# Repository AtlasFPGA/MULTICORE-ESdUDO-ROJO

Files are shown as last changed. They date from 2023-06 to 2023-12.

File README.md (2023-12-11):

# MULTICORE-ESdUDO-ROJO
Diseñar la placa - ¡Créalo tu mismo! de coste más reducido para la Fpga CYC1000 con una bluepill STM32F103C8T6

# https://t.me/INICIATIVAATLAS -> El grupo ATLAS esta en Telegram pueden encontrarnos allí, Group ATLAS in Telegram

Escudo ROJO (https://youtu.be/kMc1XR39d8Y)

   Se muestra el multicore en desarrollo para cyc1000 de arrow/trenz el cual aloja una fpga Cyclone 10 LP de intel con 25kles y 66 bloques de Bram de 9Kbytes, tiene integrada una memoria de celular de bajo consumo y reducida latencia, siendo una sdram a 166Mhz con 8MBytes en un bus de 16bits, La familia Cyclone 10 LP permite implementar modelos que superan los 400Mhz en sus diseños, manteniendo un bajo consumo. 
También hay que disponer de una bluepill con un STM32F103C8Tx, posee 64Kbytes de Flash y 20Kbytes de sram, con una unidad de proceso ARM cortex M3 de 32bit funcionando a 72Mhz. 

---
# Esquema analógico totalmente configurable por el usuario en el vídeo compuesto de 512 colores.

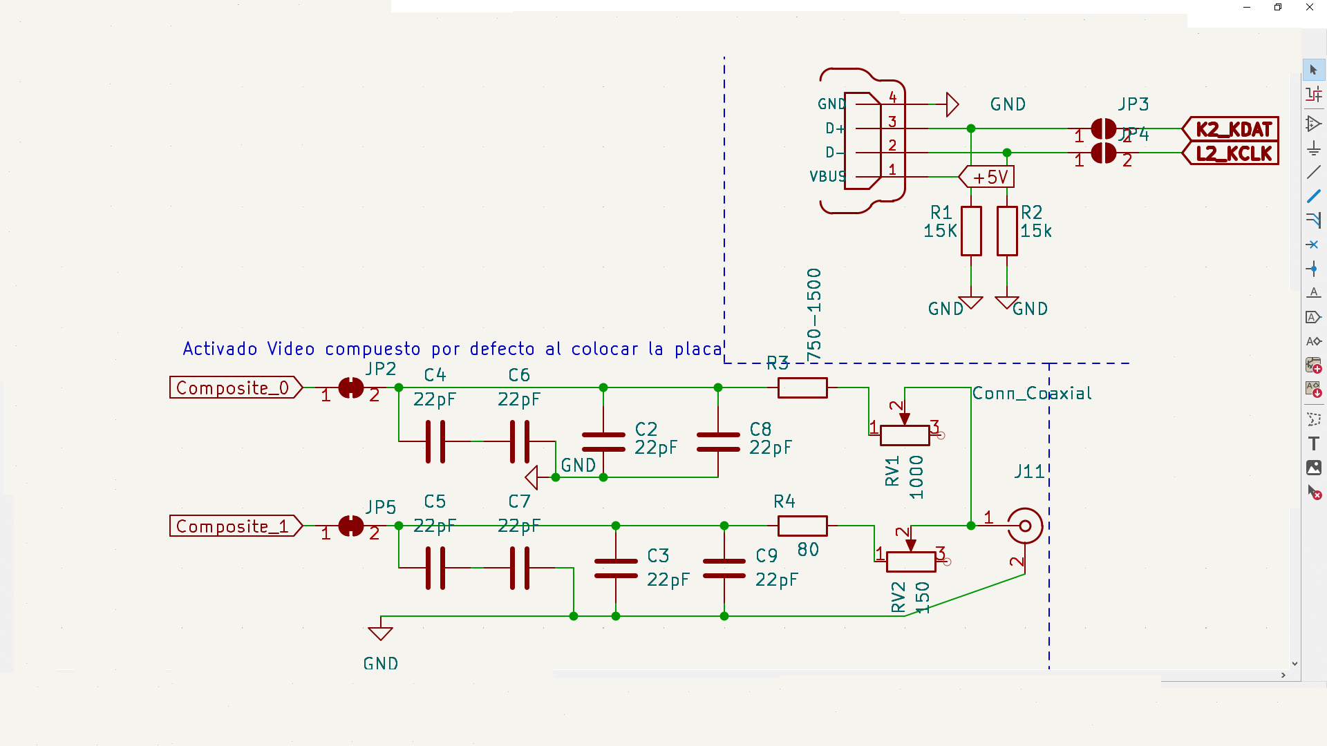
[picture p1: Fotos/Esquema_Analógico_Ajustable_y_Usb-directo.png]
Ajuste ANALÓGICO VIDEO COMPUESTO


Nota:

Creamos una tabla para proceder con el ajuste analógico de la salida de vídeo compuesto.

| R3  | RV1 | VALOR RESISTIVO RAMA COMPOSITE 0  | R4  | RV2  |  VALOR RESISTIVO RAMA COMPOSITE 1|
|:---:|---:|---:|---:|---:|---:|
|750 Ohm|0 Ohm|750 Ohm| 80 Ohm| 0 Ohm|80 Ohm|
|1500 Ohm|1000 Ohm|2500 Ohm|80 Ohm|150 Ohm|230 Ohm|

Para Composite 0 la corriente máxima se obtiene con 750 Ohm -> +3,3V/(750_Ohm)= 0,0044 Amperios

Para Composite 0 la corriente mínima se obtiene con 2500 Ohm -> +3,3V/(2500_Ohm)= 0,00132 Amperios

Para Composite 1 la corriente máxima se obtiene con 80 Ohm -> +3,3V/(80_Ohm)= 0,04125 Amperios -> La CYCLONE 10 LP esta limitada a 12Miliamperios ¿Lo fundimos?

Para Composite 1 la corriente mínima en el diseño propuesto se obtiene con 230 Ohm -> +3,3V/(230_Ohm)= 0,014347926 Amperios -> Por encima de la limitación de corriente 12Miliamperios

Luego hay que calcular que valores de resistencia usar, en Composite 1 en las dos posiciones extremas se drena más corriente por pin.
También vemos que aporta más corriente Composite1 un valor más fuerte que Composite0, por lo que tenemos bien ordenadas las lineas por donde van las señales, pero al ser hardware programable, imaginamos que nos equivocamos, esta es una de las grandes cualidades de una FPGA, con una simple reordenadión de pineado y reetiquetado todo funciona perfectamente,es por esto que muchos diseños actualmente son programables ya sean microcontroladores, cplds o fpgas.

Luego la pregunta es, que resistencia en serie a +3,3V coloco para no fundir un pin de... ¿la preciada FPGA?
doce miliamperios = 0,012_Amperios = +3,3_Voltios/Resistencia_protección_pin

Resistencia_protección_pin = 275 Ohm

Es lo más importante dado que la FPGA tiene limitada la cantidad de corriente que es capaz de entregar, y hacerle una conexión muy baja en resistencia puede fundir o dicho pin o parte de los pines de salida de la fpga, raramente toda la FPGA.

Sus resistencias se suman, la posición de las resistencias fijas es para proteger los circuitos y limitar la corriente, en realidad hemos puesto el valor represantado con el mayor valor resistivo y el menor de todos.

# Pero como siempre pasa os he mentido, porque... ¿Realmente llega a 0V cuando el televisor recoge la señal?

El caso de los condensadores/capacitores de filtrado es algo más complejo dado que las ramas que estan en serie siguen esta ley (Condensador=Capacitor):
1/Condensador_equivalente = 1/Condensador_serie1 + 1/Condensador_serie2 + 1/Condensador_serie3 + ... + 1/Condensador_serieN
Pero como vamos a usar valores del mismo condensador tenemos una rama preparada en serie.
El condensador usado para el montaje son 6 condensadores de 22 pico faradios, ya ser verán si se colocan todos o no, una capacidad bastante pequeña.
1 Mili = 0'001 Faradios
1 Nano = 0'000001 Faradios
1 Pico = 0'000000001 Faradios

Entondes en realidad usamos condensadores/capacitores de:
22 Pico Faradios = 0'000000022 Faradios

cuando hacemos y despejamos esta ecuación 1/Faradios_rama_serie = 1/0'000000022_F + 1/0'000000022_F
Sale un resultado de Faradios_rama_serie = 1/0'000000011 Faradios y en lenguaje de pico -> 11 pico Faradios

Cuando hay condensadore/capacitores en paralelo se suman sus capacidades:
Podemos no filtrar la señal -> 0Faradios pero esto nunca se cumple y menos con señales generadas a tanta frecuencia las pistas siempre tienen un contenido continuo de capacitancia, por eso siempre aparecen modelizaciones de spice.

Usando los 2 condensadores en una sola rama en serie:
Una capacidad de 11 Pico faracios.

Poniendo un Condensador de 22 picofaracios entre la señal de salida de la fpga y GND.
Una capacidad de 22 Pico faradios.

Poniendo los 2 condensadores en paralelo se suman sus capacidades, (Tampoco es verdad si los condensaores estan limitados en voltaje):
Pero bueno digamos que todo es ideal y son 44 Pico Faradios.

La maxima capacidad es usar 2 condensadores en paralelo más una rama de condensadores en serie:
22 Pico Faradios + 22 Pico Faradios + 11 Pico Faradios = 55 Pico Faradios.

Luego con 4 condensadores en la disposición del circuito podemos tener estas capacidades.

Practicamente 0 Faradios , 0'000000022 Faradios,0'000000033 Faradios ,0'000000044 Faradios y 0'000000055 Faradios
Hay un modo que he puesto su filtrado pero no esta explicado.
Pero se vé lo útil de tener la dispoción de filtrado en capacidad, por supuesto si alguien quiere filtrar más la señal puede cambiando los modelos de condensador.

Las resistencias tienen un valor fijo en R3 y R4 y al menos tendrían que limitar la corriente al máximo que permite la familia Cyclone 10 Lp.
---
# Esquema ESdUDO V0101
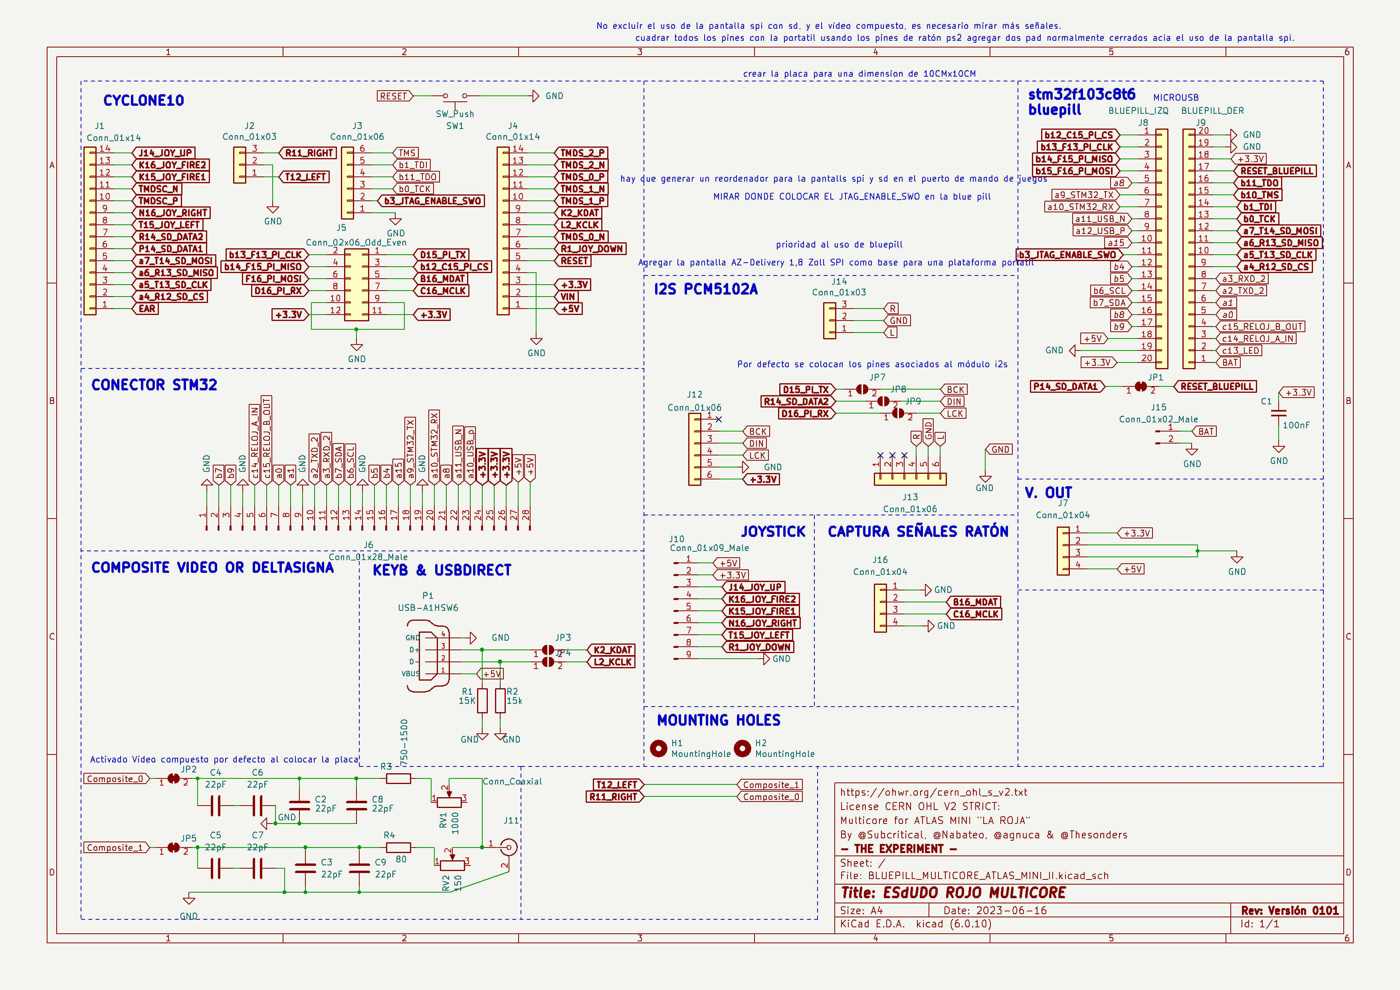
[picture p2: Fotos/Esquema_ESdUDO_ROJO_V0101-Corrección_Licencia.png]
Esquemario ESdUDO ROJO V0101

---
# Capas de la placa ESdUDO V0101
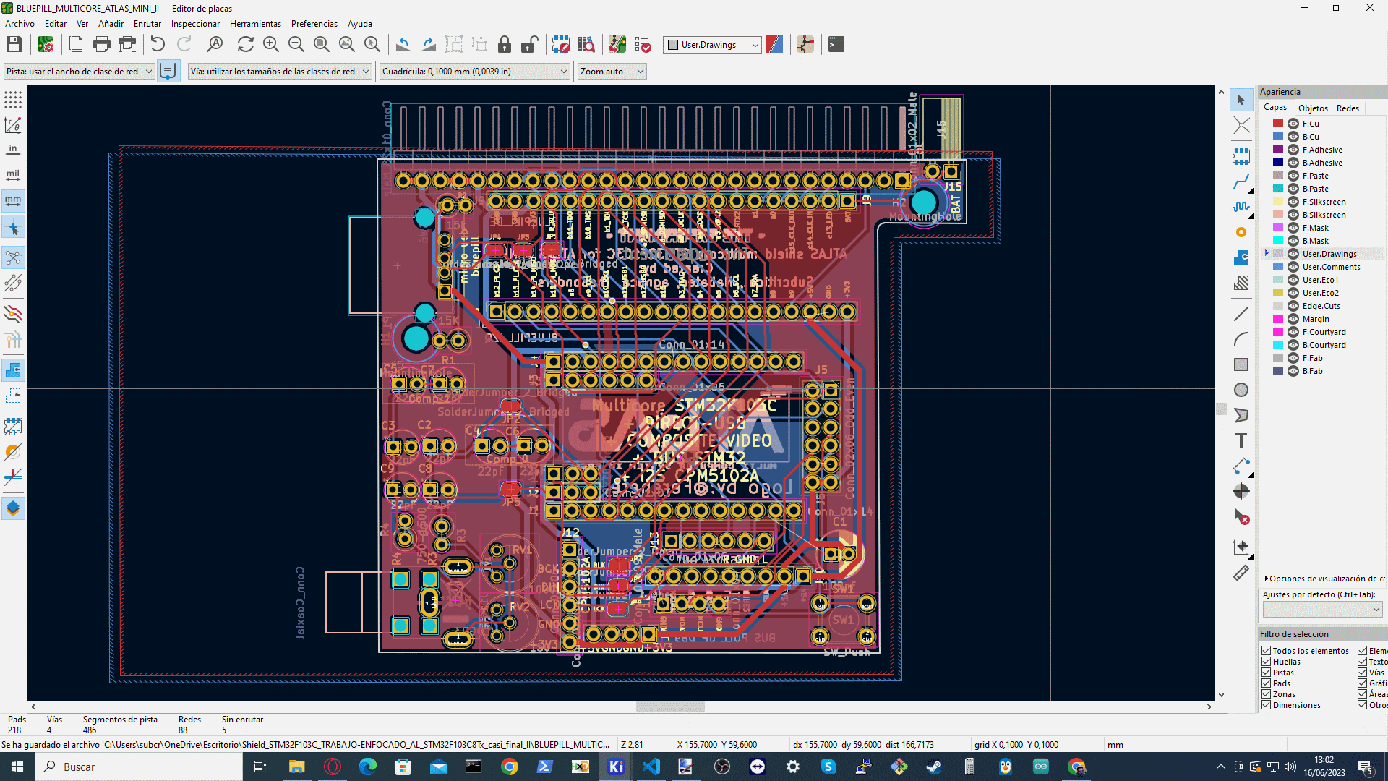
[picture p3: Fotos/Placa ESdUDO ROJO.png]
Placa ESdUDO ROJO V0101

---

   Este modelo implementa soluciones de muy baja latencia, al usar envoltorios con máquinas de estado finito para el video compuesto y el teclado.
   
###   https://github.com/TheSonders/COLOR_PAL
   
###   https://github.com/TheSonders/USBKeyboard

   El diseño es de reducido tamaño, permitiendo alojarlo en equipos estropeados y no recuperables.

   En precio asociado a la placa son aproximadamente 6€.
---

#   Una lista de los pocos componentes necesarios

| Unidades  | descripción |  Precio medio en tienda física en España |
|---|:---:|---:|
| 8 |  • condensadores de filtrado, ramas serie y paralelo. | ?€|
| 4 |  • resistencias. Dos de ellas prescindibles mediante programacion de pull down en las patillas K1 y L1 de la cyc1000. |  ?€ |
| 2 | • potenciometros de señal para ajustar la intensidad. | ?€ |
  | numerosos | • Asi como bastantes tiras de pines, machos y hembras también pines apilables usados en arduino. |    ?€ |
  | 1 | • Un condensador electrolítico. |    ?€ |
  | 1 | • Un pulsador. |    ?€ |
  | 1 | • Un puerto usb A. |    ?€ |
  | 1 | • Un puerto de vídeo compuesto. |    ?€ |
  | 1 | • Disponer de una muestra de cyc1000 del programa Europero de fpgas de intel/arrow. |    ?€ |
  | 1 | • Disponer de una bluepill. |    ?€ |
  | 1 | • Así como un módulo i2s de texas instruments MCP5102A. |    ?€ |

--- 
   Es con diferencia el sistema multicore más económico.

Las placas necesarias:

# ¡ATENCIÓN A LA BLUPILL COLOCADA! 
# HAY DOS MODELOS DE BLUEPILL, LA BLUEPILL PLUS, Y LA PRIMERA BLUEPILL.

BLUEPILL STM32F103C8T6 (Usada en el DISEÑO V0101):

https://es.aliexpress.com/item/1005003429884084.html

BLUEPILL STM32F103C8T6 Plus (Necesita adaptación una linea de 5V existe en lugar de GND, se producirá un buen corto si se opta por este modelo),
por lo demás es compatible en un rango de funcionamiento del 99% y tiene un punto que para el programador es interesante  duplica la flash disponible 128Kbytes.

https://m.es.aliexpress.com/item/1005004918334754.html

SD+TFT AZ-Delivery de 1,8Pulgadas:

https://es.aliexpress.com/item/1005005060814683.html

CYC1000 versión mejorada del 2023 TEI0003-03-QFCR4A-CYC1000:

https://shop.trenz-electronic.de/en/TEI0003-03-QFCR4A-CYC1000-with-Cyclone-10-FPGA-8-MB-SDRAM-8-MB-Flash-6.15-x-2.5-cm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

O una muestra en el programa europeo de microfpgas:

https://www.arrow.com/en/family/intel-solutions-europe

Grupo de la iniciativa ATLAS en TELEGRAM:

# https://t.me/INICIATIVAATLAS

Licencia CERN OHL V2 STRICT:

https://ohwr.orgcern_ohl_s_v2.txt

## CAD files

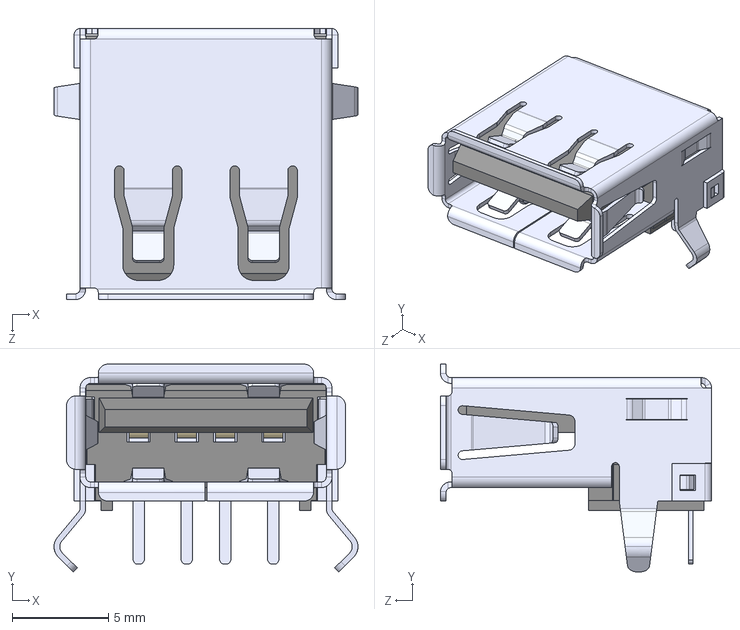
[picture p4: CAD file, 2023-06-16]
KICAD/Versión0101/HUELLAS_3d_models/USB/USB-A1HSW6.step
15.8 x 10.8 x 14.1 mm

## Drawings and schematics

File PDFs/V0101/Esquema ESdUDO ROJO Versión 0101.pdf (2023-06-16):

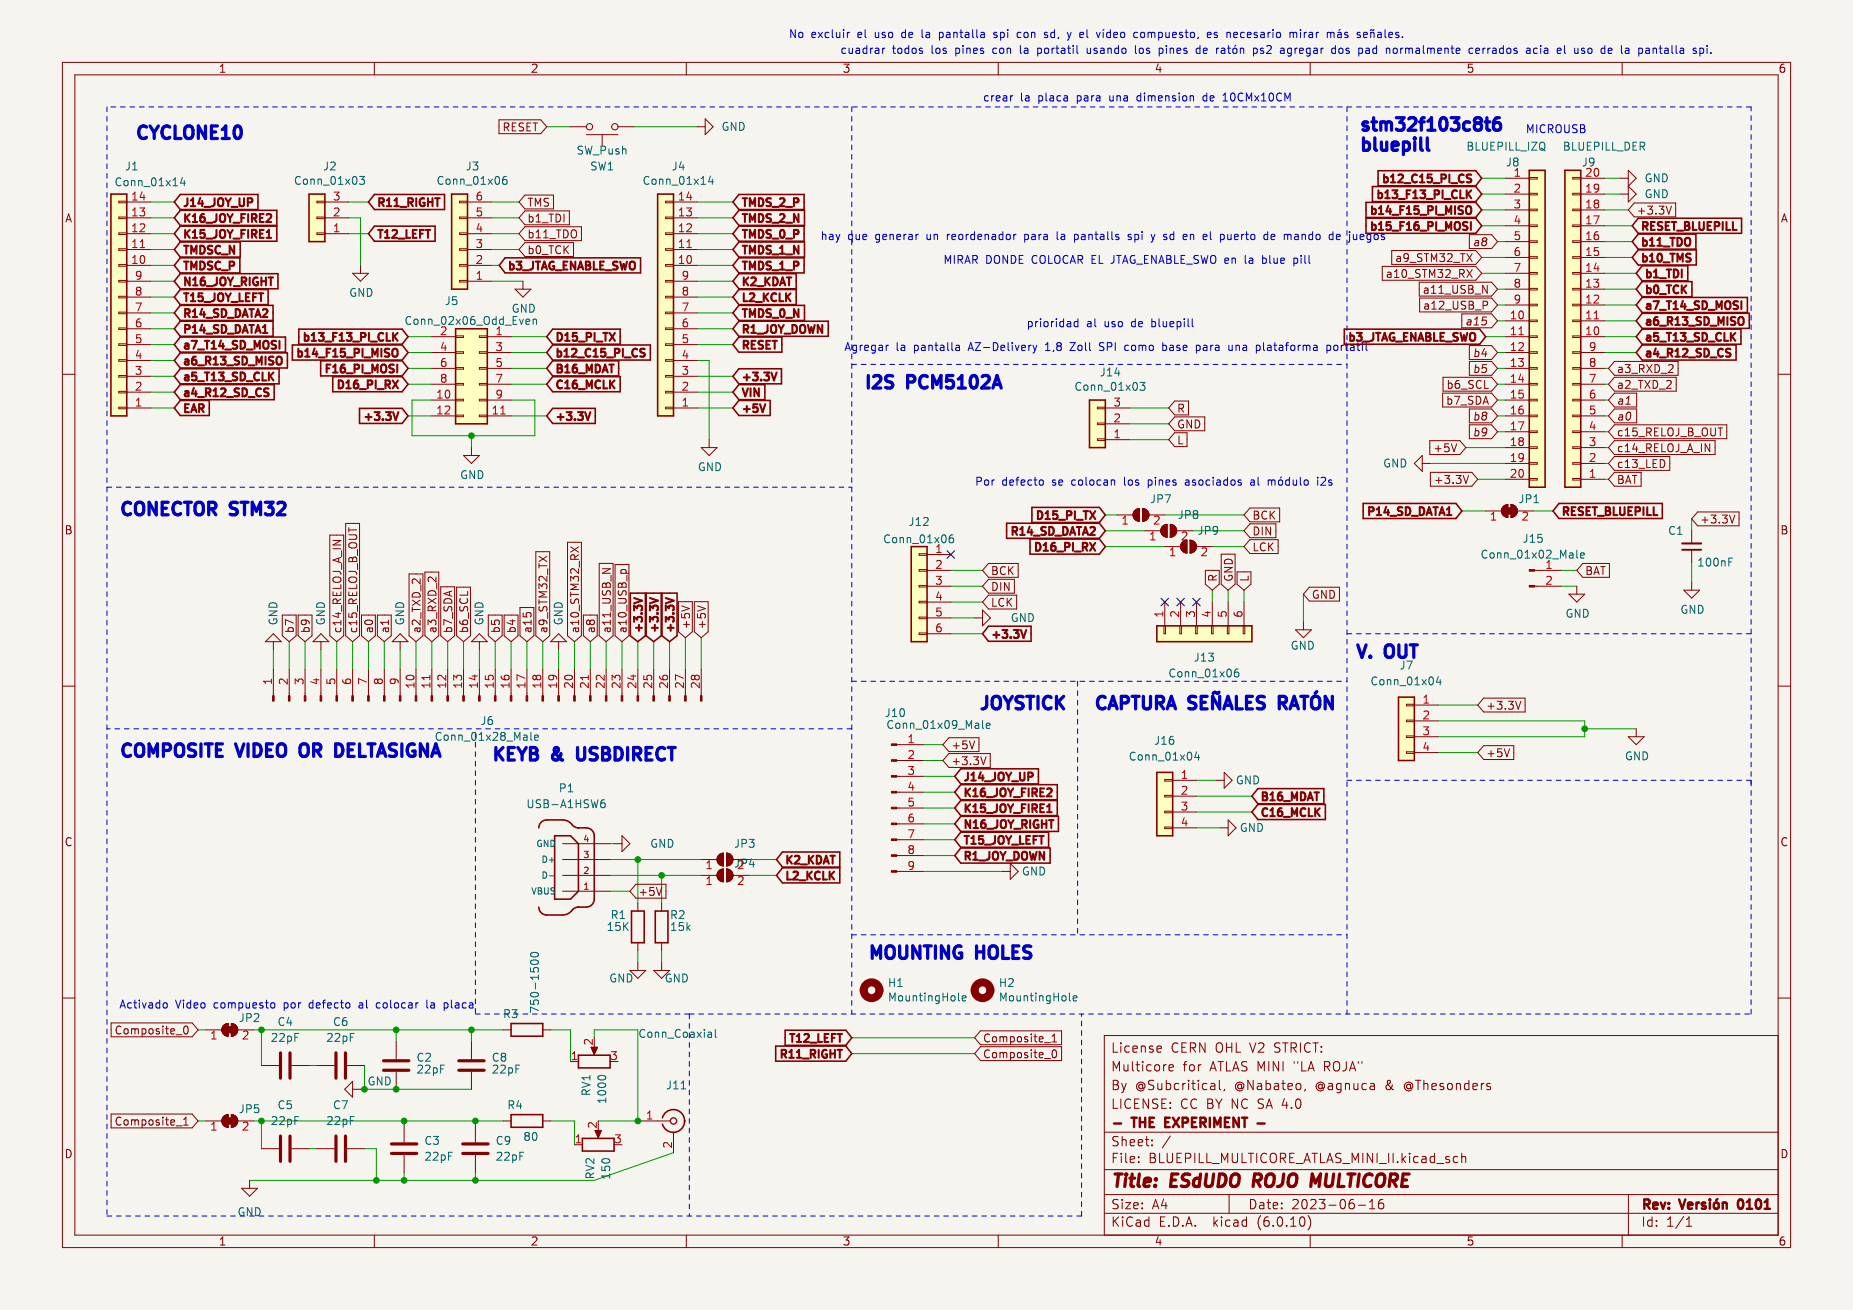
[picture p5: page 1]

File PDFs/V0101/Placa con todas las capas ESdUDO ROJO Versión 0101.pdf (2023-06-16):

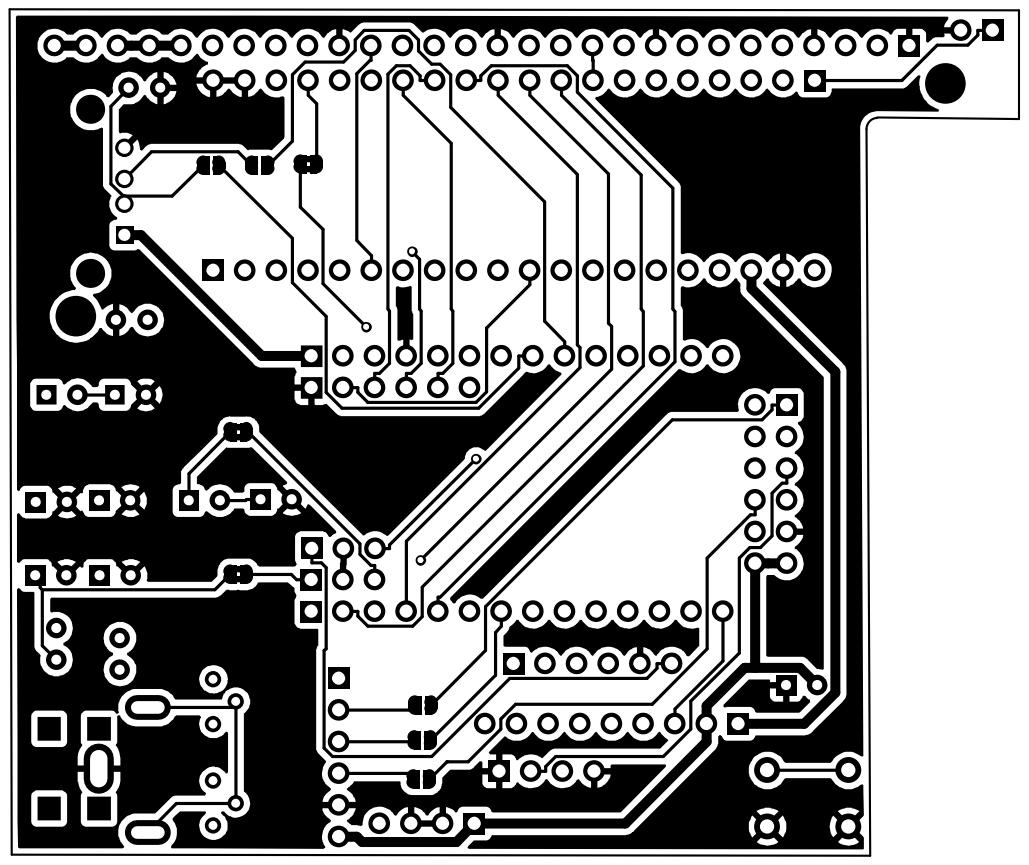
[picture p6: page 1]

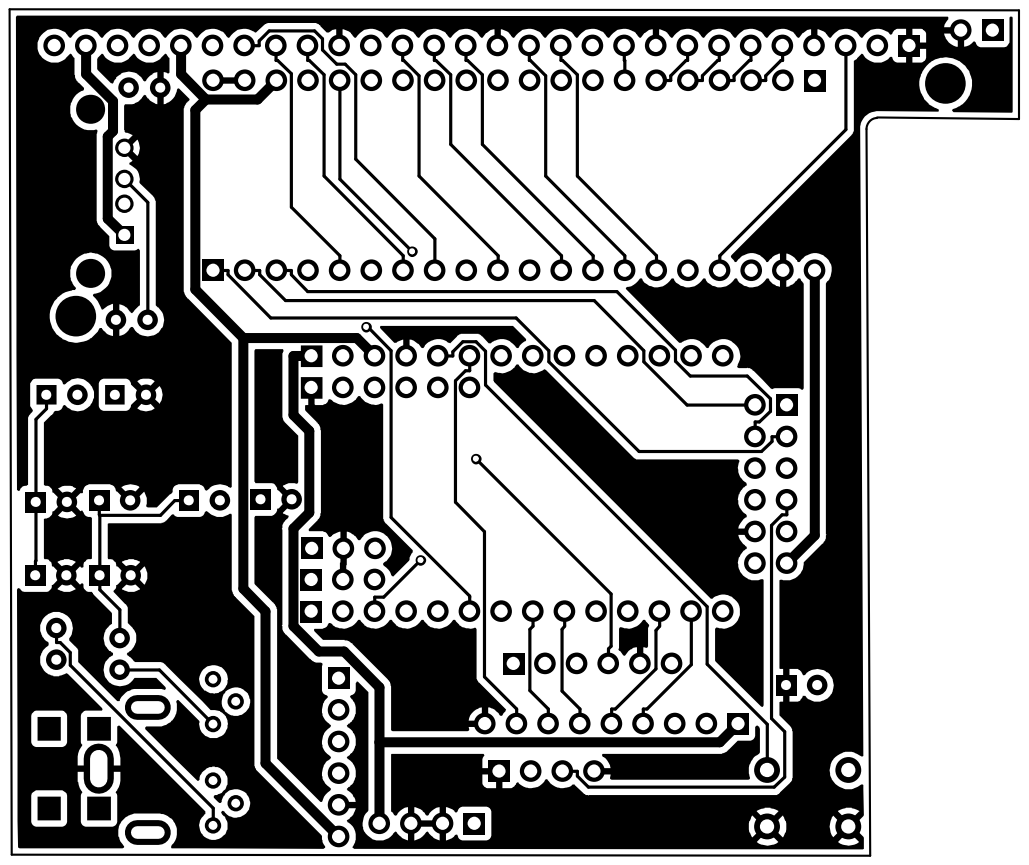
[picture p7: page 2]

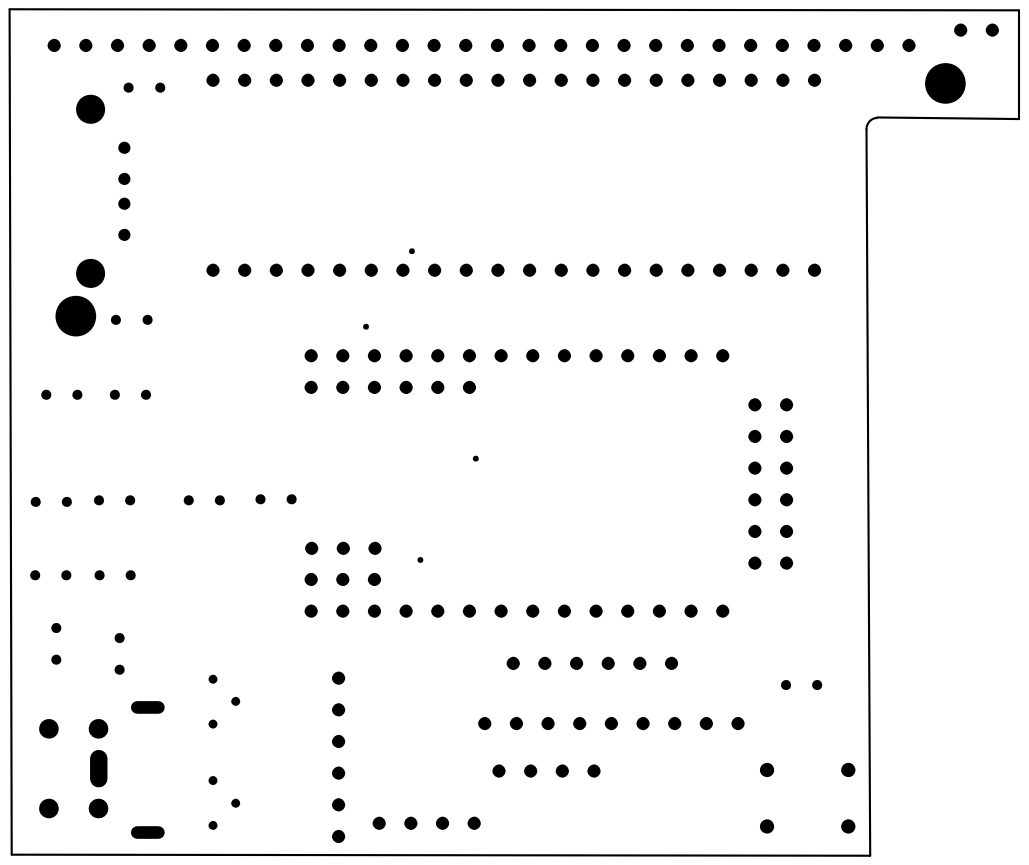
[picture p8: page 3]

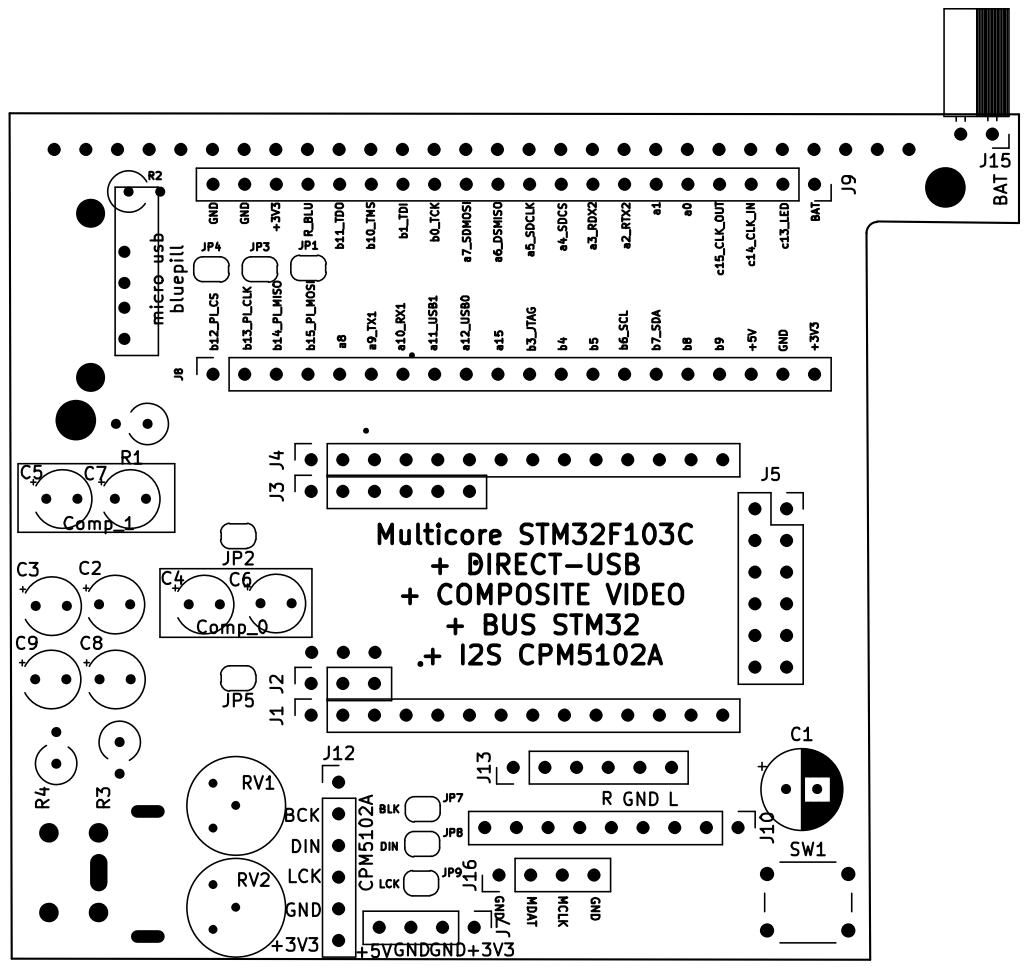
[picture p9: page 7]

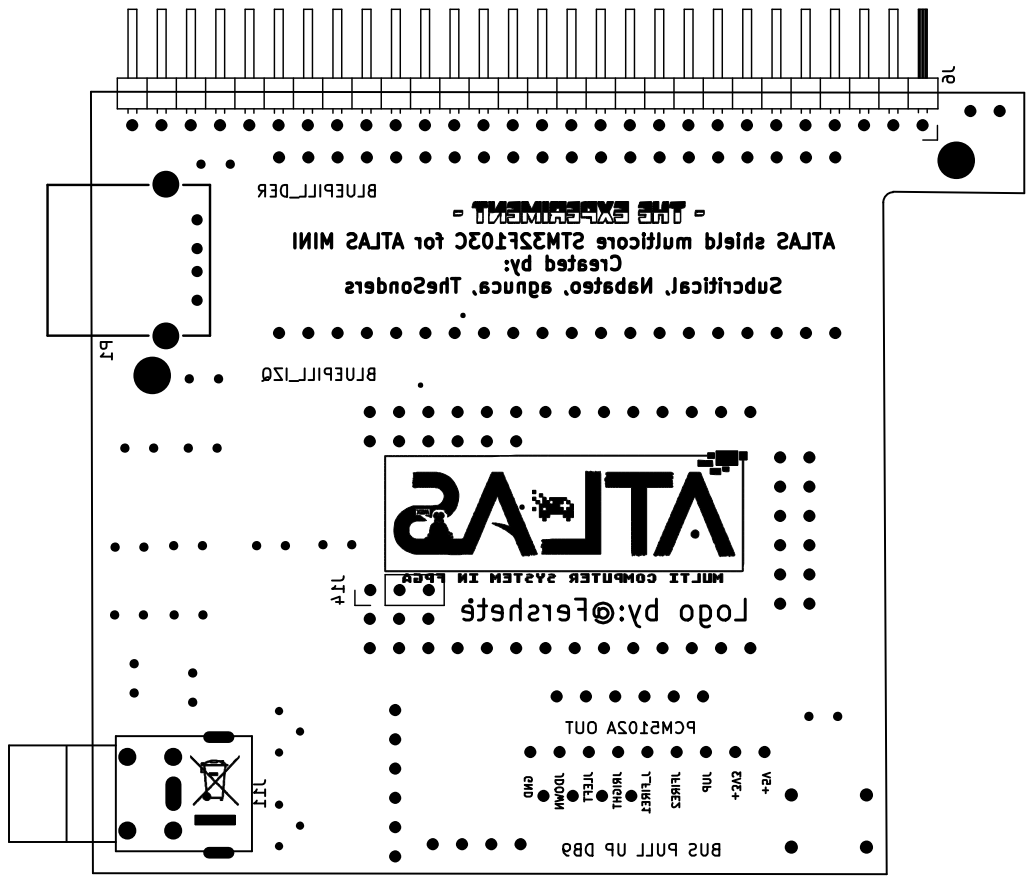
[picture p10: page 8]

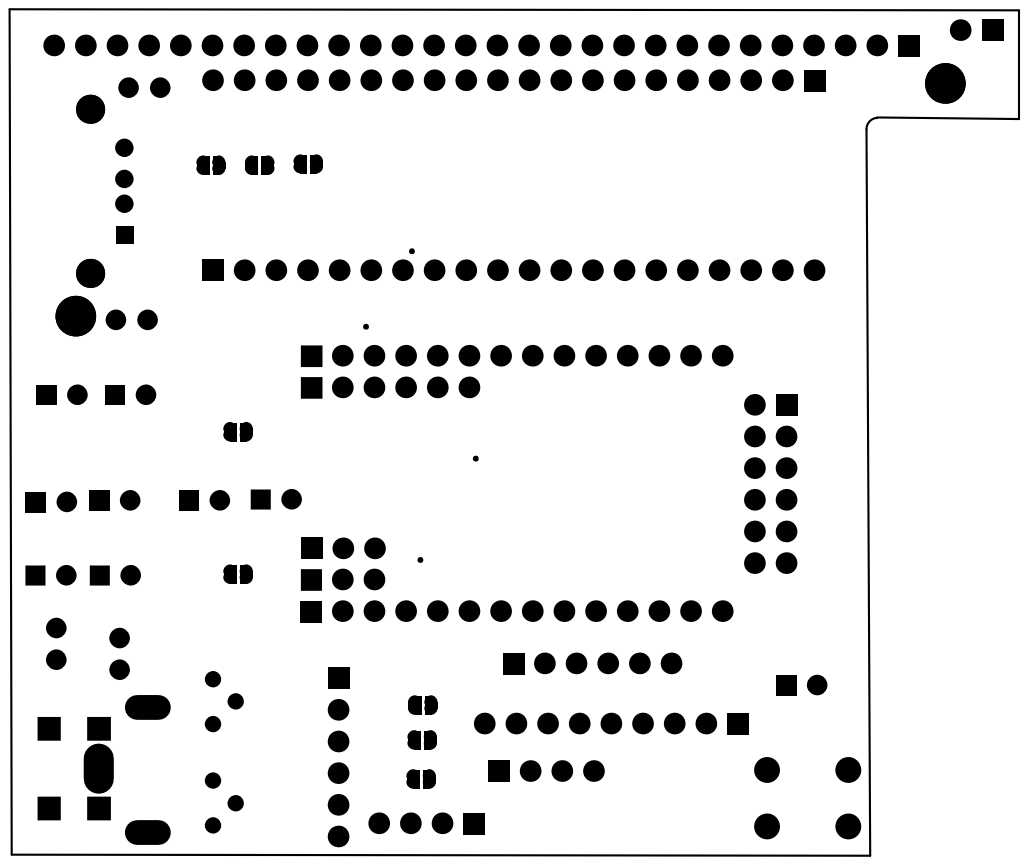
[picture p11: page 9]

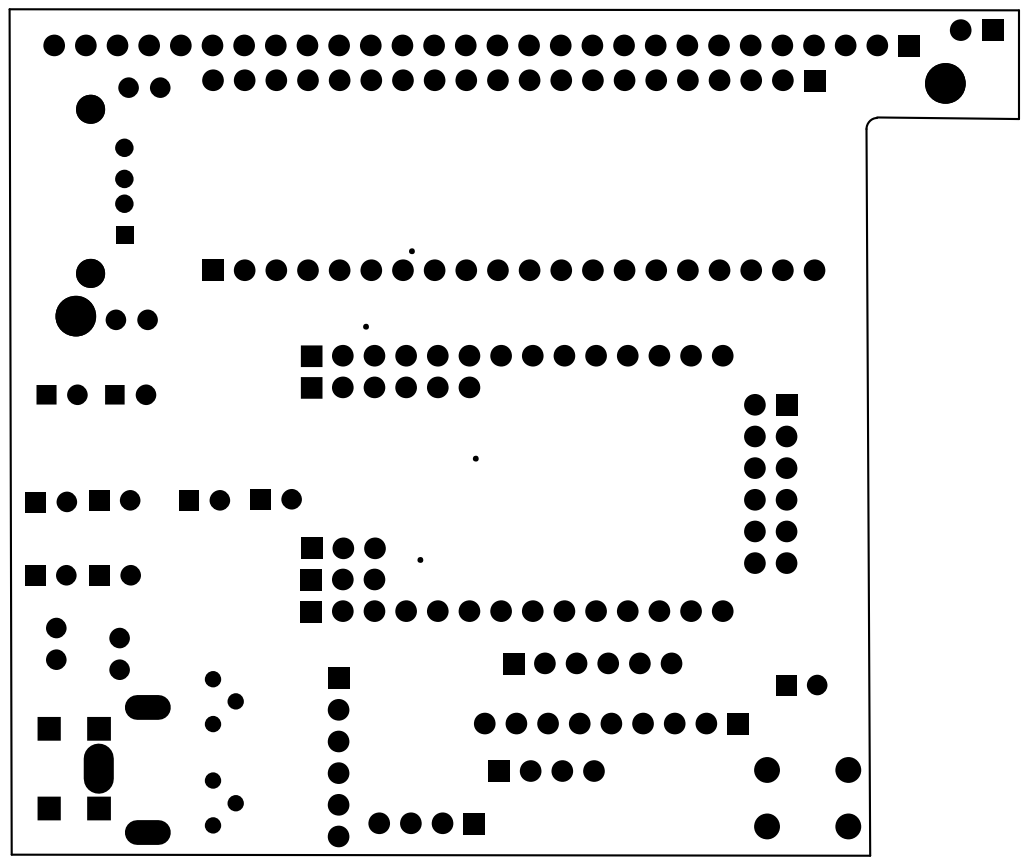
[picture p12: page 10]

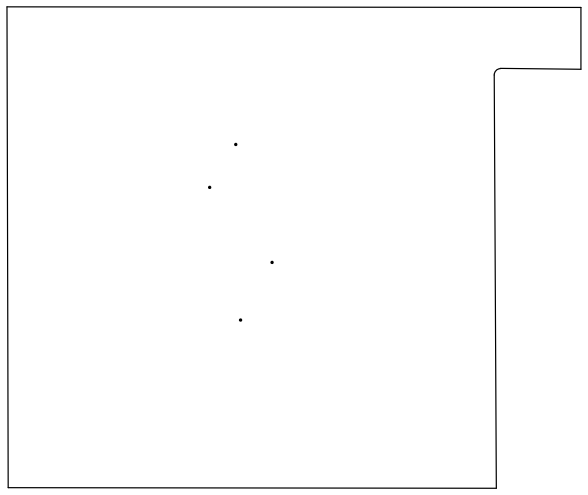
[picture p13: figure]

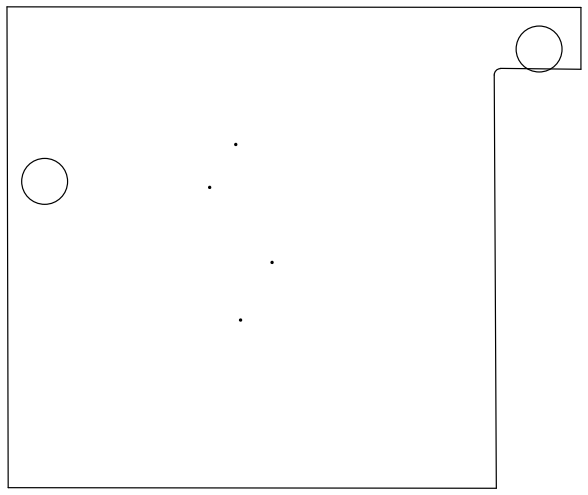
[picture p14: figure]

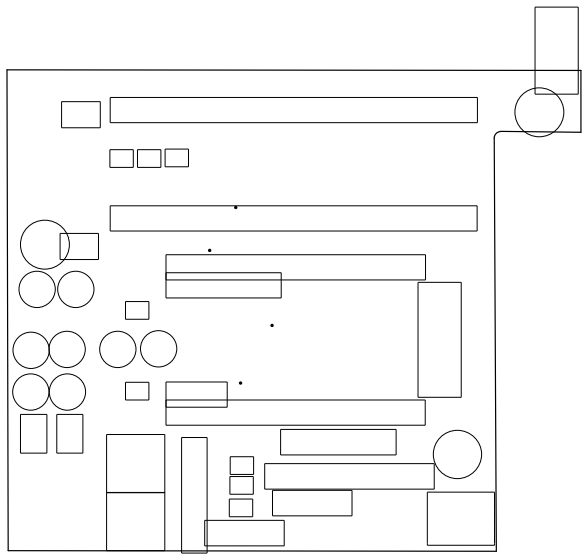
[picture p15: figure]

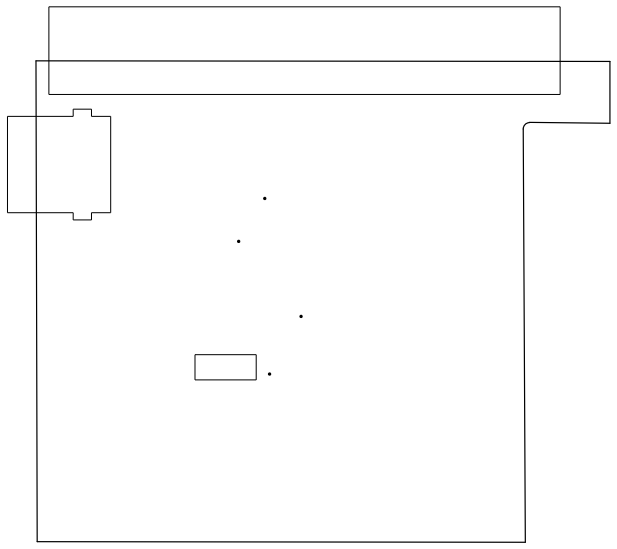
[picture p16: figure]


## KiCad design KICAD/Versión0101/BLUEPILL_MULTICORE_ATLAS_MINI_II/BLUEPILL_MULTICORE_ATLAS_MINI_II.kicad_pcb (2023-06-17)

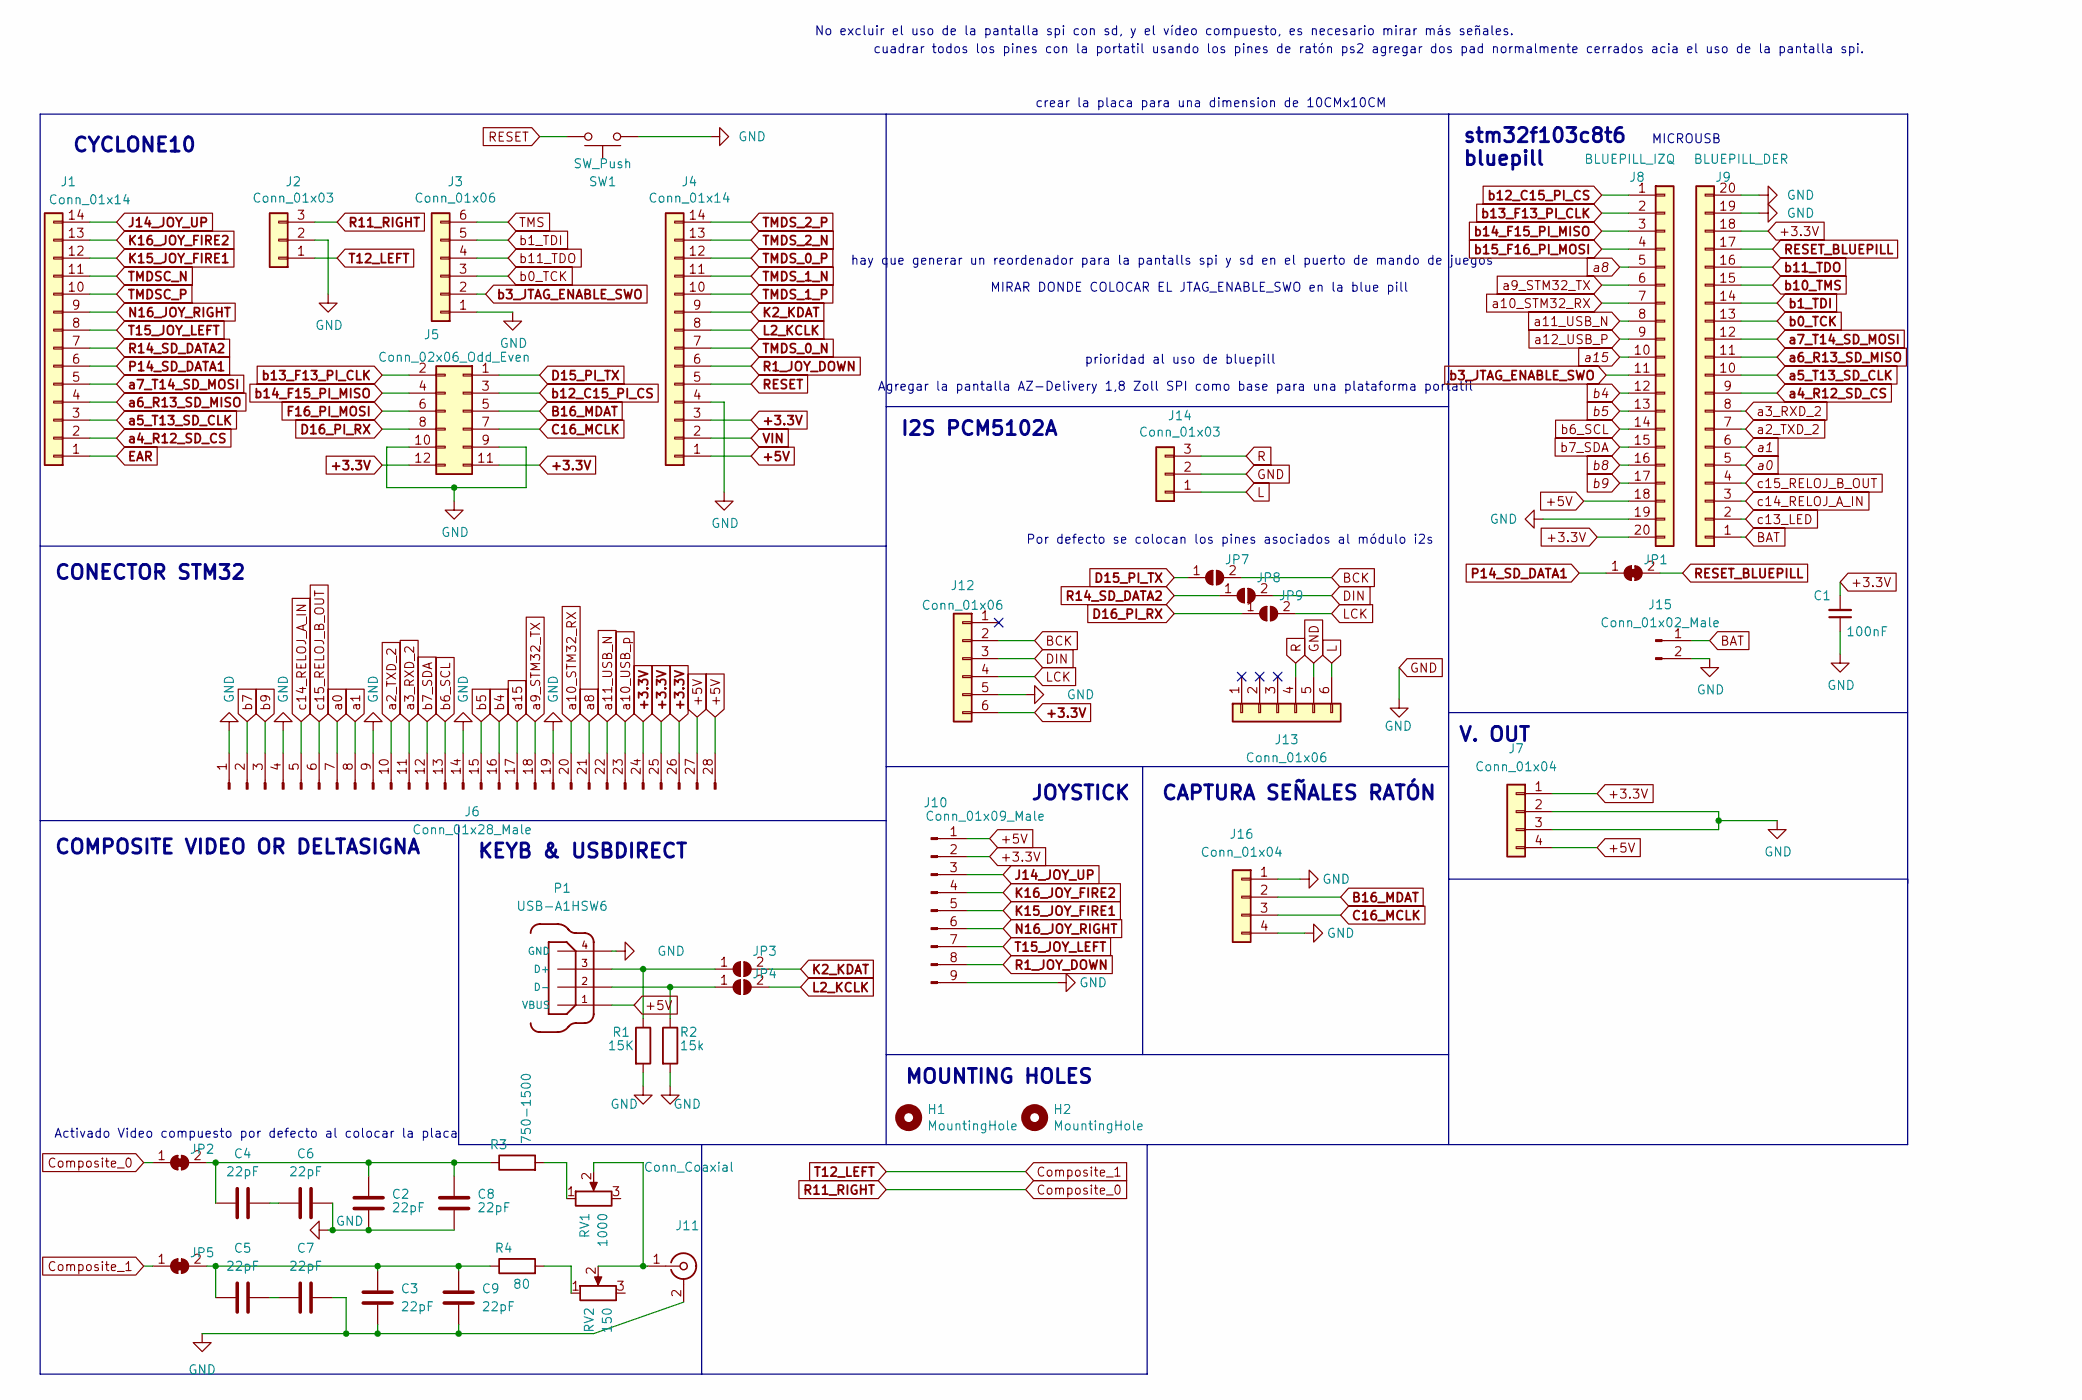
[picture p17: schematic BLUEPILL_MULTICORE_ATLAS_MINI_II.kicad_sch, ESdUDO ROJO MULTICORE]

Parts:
C1: 100nF; CP_Radial_D6.3mm_P2.50mm
C2, C3, C4, C5, C6, C7, C8, C9: 22pF; CP_Radial_Tantal_D4.5mm_P2.50mm
H1, H2: MountingHole; MountingHole_3.2mm_M3
J1, J4: Conn_01x14; PinSocket_1x14_P2.54mm_Vertical
J2, J14: Conn_01x03; PinSocket_1x03_P2.54mm_Vertical
J3: Conn_01x06; PinSocket_1x06_P2.54mm_Vertical
J5: Conn_02x06_Odd_Even; PinSocket_2x06_P2.54mm_Vertical
J6: Conn_01x28_Male; PinHeader_1x28_P2.54mm_Horizontal
J7, J16: Conn_01x04; PinHeader_1x04_P2.54mm_Vertical
J8: BLUEPILL_IZQ; PinSocket_1x20_P2.54mm_Vertical
J9: BLUEPILL_DER; PinSocket_1x20_P2.54mm_Vertical
J10: Conn_01x09_Male; PinHeader_1x09_P2.54mm_Vertical
J11: Conn_Coaxial; rca_combined
J12, J13: Conn_01x06; PinHeader_1x06_P2.54mm_Vertical
J15: Conn_01x02_Male; PinSocket_1x02_P2.54mm_Horizontal
JP1, JP2, JP5: SolderJumper_2_Bridged; SolderJumper-2_P1.3mm_Bridged2Bar_RoundedPad1.0x1.5mm
JP3, JP4, JP7, JP8, JP9: SolderJumper_2_Open; SolderJumper-2_P1.3mm_Open_RoundedPad1.0x1.5mm
P1: USB-A1HSW6; OST_USB-A1HSW6
R1: 15K; R_Axial_DIN0309_L9.0mm_D3.2mm_P2.54mm_Vertical
R2: 15k; R_Axial_DIN0309_L9.0mm_D3.2mm_P2.54mm_Vertical
R3: 750-1500; R_Axial_DIN0309_L9.0mm_D3.2mm_P2.54mm_Vertical
R4: 80; R_Axial_DIN0309_L9.0mm_D3.2mm_P2.54mm_Vertical
RV1: 1000; Potentiometer_Bourns_3339H_Vertical
RV2: 150; Potentiometer_Bourns_3339H_Vertical
SW1: SW_Push; SW_PUSH_6mm

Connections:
+3.3V: C1.2, J4.3, J5.11, J5.12, J6.24, J6.25, J6.26, J7.1, J8.20, J9.18, J10.2, J12.6
+5V: J4.1, J6.27, J6.28, J7.4, J8.18, J10.1, P1.1 (VBUS)
B16_MDAT: J5.5, J16.2
BAT: J9.1, J15.1
BCK: J12.2, JP7.2 (B)
C16_MCLK: J5.7, J16.3
Composite_0: J2.3, JP2.1 (A)
Composite_1: J2.1, JP5.1 (A)
D15_PI_TX: J5.1, JP7.1 (A)
D16_PI_RX: J5.8, JP9.1 (A)
DIN: J12.3, JP8.2 (B)
EAR: J1.1
F16_PI_MOSI: J5.6
GND: C1.1, C2.2, C3.2, C6.2, C7.2, C8.2, C9.2, J2.2, J3.1, J4.4, J5.9, J5.10, J6.1, J6.4, J6.9, J6.14, J6.19, J7.2, J7.3, J8.19, J9.19, J9.20, J10.9, J11.2 (Ext), J12.5, J13.5, J14.2, J15.2, J16.1, J16.4, P1.4 (GND), R1.2, R2.2, SW1.2
J14_JOY_UP: J1.14, J10.3
K2_KDAT: J4.9, JP3.2 (B)
K15_JOY_FIRE1: J1.12, J10.5
K16_JOY_FIRE2: J1.13, J10.4
L: J13.6, J14.1
L2_KCLK: J4.8, JP4.2 (B)
LCK: J12.4, JP9.2 (B)
N16_JOY_RIGHT: J1.9, J10.6
unnamed: C2.1, C4.1, C8.1, JP2.2 (B), R3.1
unnamed: C3.1, C5.1, C9.1, JP5.2 (B), R4.1
unnamed: C4.2, C6.1
unnamed: C5.2, C7.1
unnamed: J11.1 (In), RV1.2, RV2.2
unnamed: JP3.1 (A), P1.3 (D+), R1.1
unnamed: JP4.1 (A), P1.2 (D-), R2.1
unnamed: R3.2, RV1.1
unnamed: R4.2, RV2.1
P14_SD_DATA1: J1.6, JP1.1 (A)
R: J13.4, J14.3
R1_JOY_DOWN: J4.6, J10.8
R14_SD_DATA2: J1.7, JP8.1 (A)
RESET: J4.5, SW1.1
RESET_BLUEPILL: J9.17, JP1.2 (B)
T15_JOY_LEFT: J1.8, J10.7
TMDSC_N: J1.11
TMDSC_P: J1.10
TMDS_0_N: J4.7
TMDS_0_P: J4.12
TMDS_1_N: J4.11
TMDS_1_P: J4.10
TMDS_2_N: J4.13
TMDS_2_P: J4.14
TMS: J3.6
VIN: J4.2
a0: J6.7, J9.5
a1: J6.8, J9.6
a2_TXD_2: J6.10, J9.7
a3_RXD_2: J6.11, J9.8
a4_R12_SD_CS: J1.2, J9.9
a5_T13_SD_CLK: J1.3, J9.10
a6_R13_SD_MISO: J1.4, J9.11
a7_T14_SD_MOSI: J1.5, J9.12
a8: J6.21, J8.5
a9_STM32_TX: J6.18, J8.6
a10_STM32_RX: J6.20, J8.7
a10_USB_p: J6.23
a11_USB_N: J6.22, J8.8
a12_USB_P: J8.9
a15: J6.17, J8.10
b0_TCK: J3.3, J9.13
b1_TDI: J3.5, J9.14
b3_JTAG_ENABLE_SWO: J3.2, J8.11
b4: J6.16, J8.12
b5: J6.15, J8.13
b6_SCL: J6.13, J8.14
b7: J6.2
b7_SDA: J6.12, J8.15
b8: J8.16
b9: J6.3, J8.17
b10_TMS: J9.15
b11_TDO: J3.4, J9.16
b12_C15_PI_CS: J5.3, J8.1
b13_F13_PI_CLK: J5.2, J8.2
b14_F15_PI_MISO: J5.4, J8.3
b15_F16_PI_MOSI: J8.4
c13_LED: J9.2
c14_RELOJ_A_IN: J6.5, J9.3
c15_RELOJ_B_OUT: J6.6, J9.4

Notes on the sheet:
No excluir el uso de la pantalla spi con sd, y el vídeo compuesto, es necesario mirar más señales.
Por defecto se colocan los pines asociados al módulo i2s
hay que generar un reordenador para la pantalls spi y sd en el puerto de mando de juegos
prioridad al uso de bluepill
MICROUSB
stm32f103c8t6 bluepill
I2S PCM5102A
CYCLONE10
KEYB & USBDIRECT
Agregar la pantalla AZ-Delivery 1,8 Zoll SPI como base para una plataforma portatil
V. OUT
crear la placa para una dimension de 10CMx10CM
COMPOSITE VIDEO OR DELTASIGNA
Activado Video compuesto por defecto al colocar la placa
CAPTURA SEÑALES RATÓN
MIRAR DONDE COLOCAR EL JTAG_ENABLE_SWO en la blue pill
MOUNTING HOLES
JOYSTICK
cuadrar todos los pines con la portatil usando los pines de ratón ps2 agregar dos pad normalmente cerrados acia el uso de la pantalla spi.
CONECTOR STM32

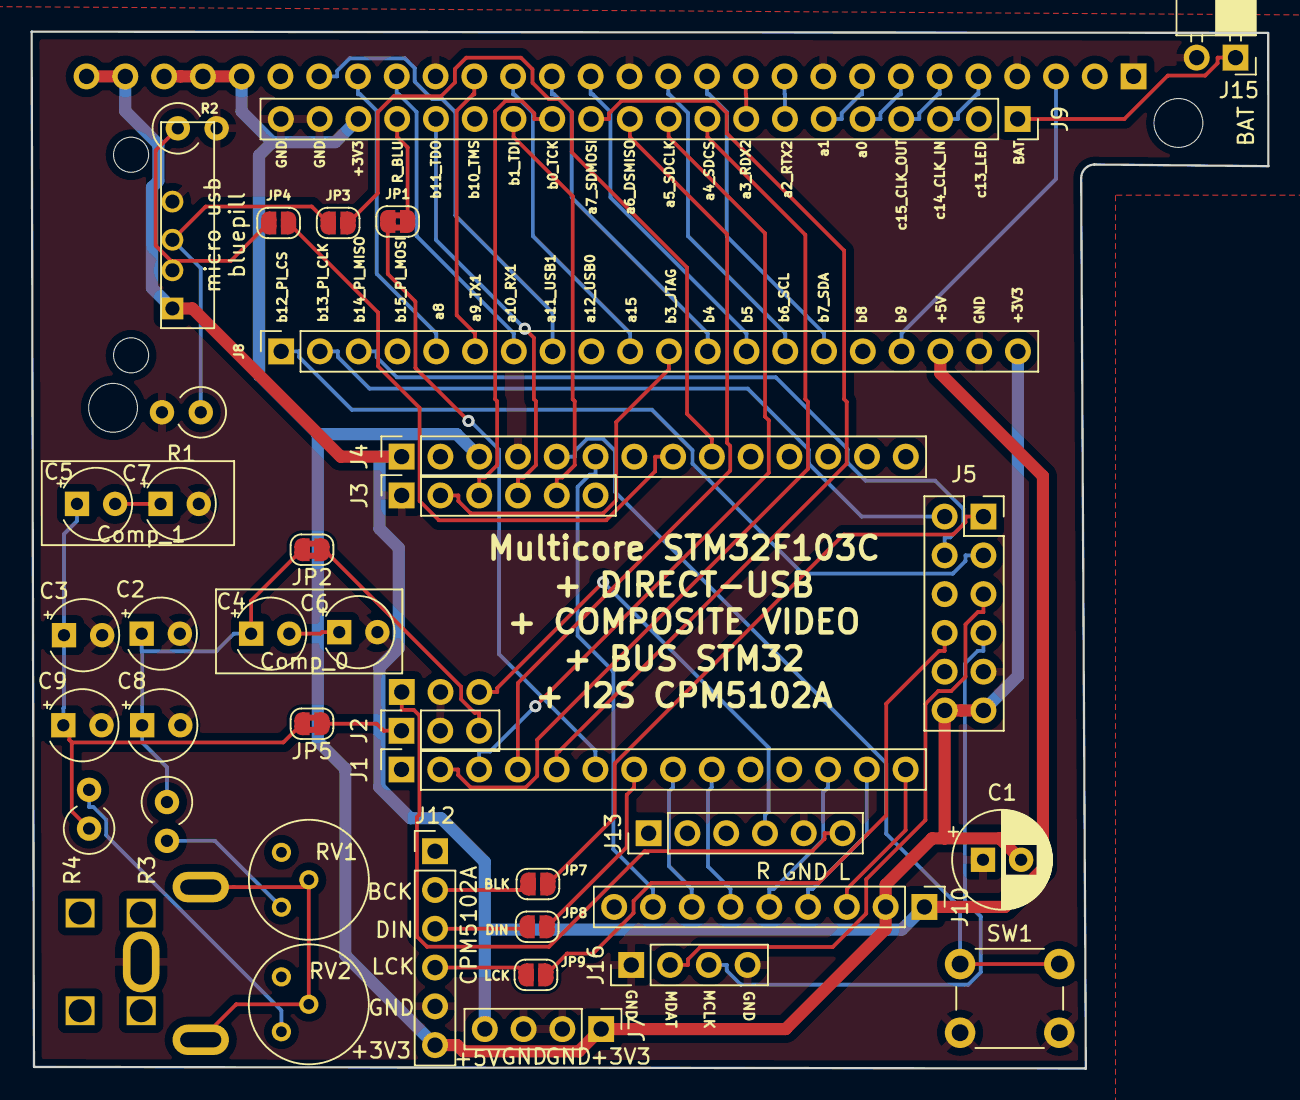
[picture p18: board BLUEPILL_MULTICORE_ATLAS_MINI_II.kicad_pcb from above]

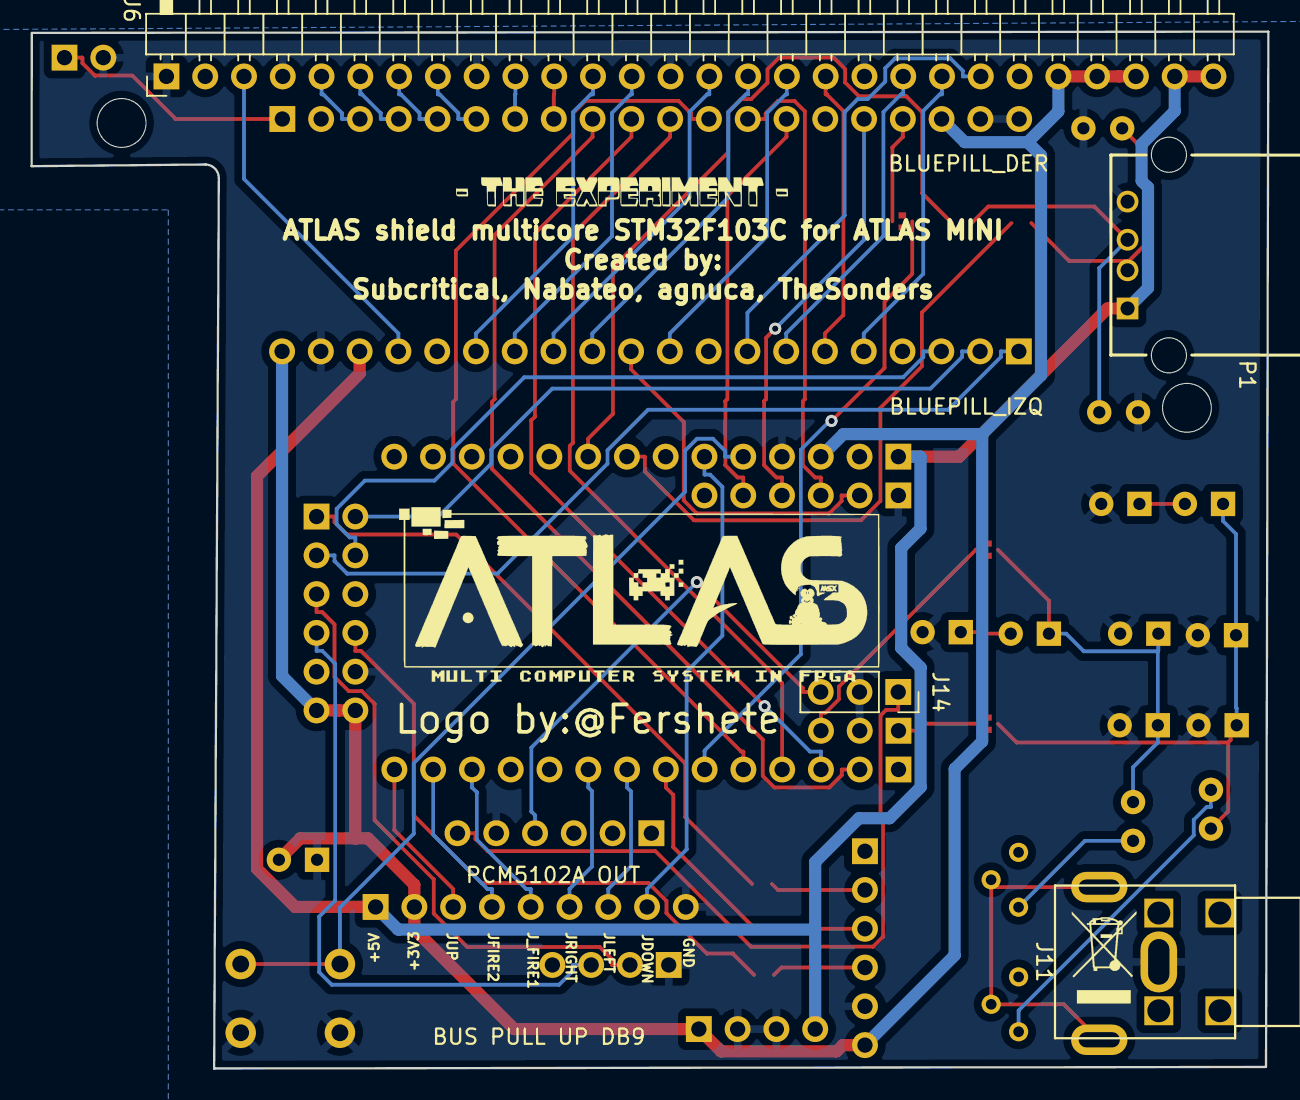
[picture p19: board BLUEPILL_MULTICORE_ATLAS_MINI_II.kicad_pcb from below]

Board: 2 copper layers, 81.0 x 67.9 mm, 44 parts (5 on the bottom side), 63 nets.

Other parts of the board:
LOGO: The experiment; Logo_Experiment

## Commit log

2023-06-16 Crear la primera información de ESCUDO ROJO la primera placa multicore por debajo de los 10€
2023-06-16 Agregar información del conversor de Digital a analógico de Texas Instrumentes PCM5102A
2023-06-16 Agregar información de ESDUDO ROJO
2023-06-16 Limpiar la información suministrada en el fichero readme, y agregar el dac PCM5102A
2023-06-16 Subir la guía de usuario de la microfpga CYC1000
2023-06-16 Agregar información sobre el chip asociado a la pantalla recomendada, chips spi para pantallas TFTs ST7789 y ST7735 del fabricante Samsung.
2023-06-16 Mejorar la redacción de ESDUDO-ROJO
2023-06-16 Crear direcctorio de kicad del ESdUDO Multicore
2023-06-16 Posicionamiento de la primera versión remitida a GITHUB.
2023-06-16 Agregar información al diseño de Kicad
2023-06-16 Agregar información al diseño de Kicad en este caso huellas muy usadas entre ellas el Euroconector
2023-06-16 Multitud de modelos 3d, entre ellos la modelización del vídeo compuesto, bus internacional por excelencia para mostrar imágen, el origen de lo retro.
2023-06-16 Posición donde estan las sesiones de spectra.
2023-06-16 las sesiones de spectra de la versión 0101 de ESdUDO ROJO.
    [BLUEPILL_MULTICORE_ATLAS_MINI.dsn]
2023-06-16 Directorio donde se alojan los modelos 3D de un usb A estandarizado, y su simbolo como huella asociada.
2023-06-16 Modelo USB usado para la representación tridimensional del Multicore ESdUDO ROJO.
    [USB-A1HSW6.step]
2023-06-16 Directorio donde se encuentra la versión 0101, queda limpiarla y reordenar todo el proyecto.
2023-06-16 Ficheros del proyecto ESdUDO Versión 0101, queda mucho por mejorar, pero este es un primer avance.
    [BLUEPILL_MULTICORE_ATLAS_MINI_II.dsn, BLUEPILL_MULTICORE_ATLAS_MINI_II.kicad_pcb, BLUEPILL_MULTICORE_ATLAS_MINI_II.kicad_sch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]
2023-06-16 Diseño de una salida totalmente analógica para el vídeo compuesto
2023-06-16 Agregada información sobre la configuración del vídeo compuesto totalmente configurable de ESdUDO ROJO.
2023-06-16 Posición donde se alojan los diagramas y la pcb con todas las capas en formato pdf.
2023-06-16 Agrego los diagramas y la placa ESdUDO ROJO con todas las capas, ambas en formato pdf.
2023-06-16 Subidos pantallazos de la Versión 0101 de la placa ESdUDO ROJO.
2023-06-16 Agregar información referente a la placa y diagrama del ESdUDO
2023-06-17 Corregir fallos en el encabezado de la descripción
2023-06-17 Modificada entrada de compra económica de BLUEPILL
2023-06-17 Aclarar que se necesita una ligera modificación para el uso de la BLUEPILL PLUS
2023-06-17 Subida versión para blupill clásica y con corrección licencia
    Aclarar que la licencia es la licencia más fuerte CERN OHL S V2:
    Licencia:
    https://ohwr.orgcern_ohl_s_v2.txt
2023-06-17 Corregir información sobre la licencia del proyecto
    CERN OHL V2 STRICT
    https://github.com/AtlasFPGA/MULTICORE-ESDUDO-ROJO/blob/main/Fotos/Esquema_ESdUDO_ROJO_V0101-Correcci%C3%B3n_Licencia.png
2023-06-17 Agregar información sobre el mundo de la BLUEPILL
2023-06-17 agregar correcto esquema para la version V0101
2023-06-17 Mejorar la redacción del README
2023-06-17 Ultima versión correcta de cache lib de kicad ESdUDO
2023-06-17 Versión ESdUDO para BLUEPILL original.
    [BLUEPILL_MULTICORE_ATLAS_MINI_II.dsn, BLUEPILL_MULTICORE_ATLAS_MINI_II.kicad_pcb, BLUEPILL_MULTICORE_ATLAS_MINI_II.kicad_sch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]
2023-06-17 Mejora de la redacción del Léeme de ESdUDO
2023-06-18 En esta carpeta se alojan los ficheros Step tridimensionales usados en la representación del montaje
2023-06-18 Fichero STEP de la CYC1000 TEI0003-02
2023-06-18 Directorio donde esta el step del USB A
2023-06-18 Huella de dos dimensiones y tres dimensiones asociado al USB A
    [USB-A1HSW6.step]
2023-06-18 En este directorio se muestra las huellas bidimensionales y tridimensionales del conector de video compuesto
2023-06-18 Agregar información del uso de la matriz de condensadores y resistencia en paralelo con potenciómetro
2023-06-18 Corregir error tabla resistencias salida vídeo compuesto
2023-06-18 Separar frases del cálculo de valores resistivos
2023-06-18 Modificar texto que habla de las corrientes drenadas por pin
2023-06-18 Mejorar explicación de ramas de capacidad en los condensadores
2023-06-18 Mejorar el objetivo de protección de corriente de los pines de la salida de vídeo compuesto.
2023-06-18 La pregunta importante sobre la caída de voltaje en el aparato receptor de la señal.
2023-06-18 Corregir corriente mínima en la linea Composite1
2023-06-18 Fichero Comprimido STEP de la primera BLUEPILL con el STM32F103C8T6
    He comprimido el fichero porque son aproximadamente 80Mbytes de diseño, cuando lo agreguéis al diseño en Kicad, esperar porque tarda un ratín.
2023-06-18 Poner en negrita la dirección de grupo DE INICIATIVA ATLAS

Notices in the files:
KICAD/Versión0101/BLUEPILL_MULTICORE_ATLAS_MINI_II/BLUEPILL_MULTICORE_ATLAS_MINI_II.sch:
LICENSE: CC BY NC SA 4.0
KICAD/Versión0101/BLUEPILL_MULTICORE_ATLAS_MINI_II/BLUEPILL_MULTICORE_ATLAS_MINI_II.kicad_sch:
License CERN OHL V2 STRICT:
